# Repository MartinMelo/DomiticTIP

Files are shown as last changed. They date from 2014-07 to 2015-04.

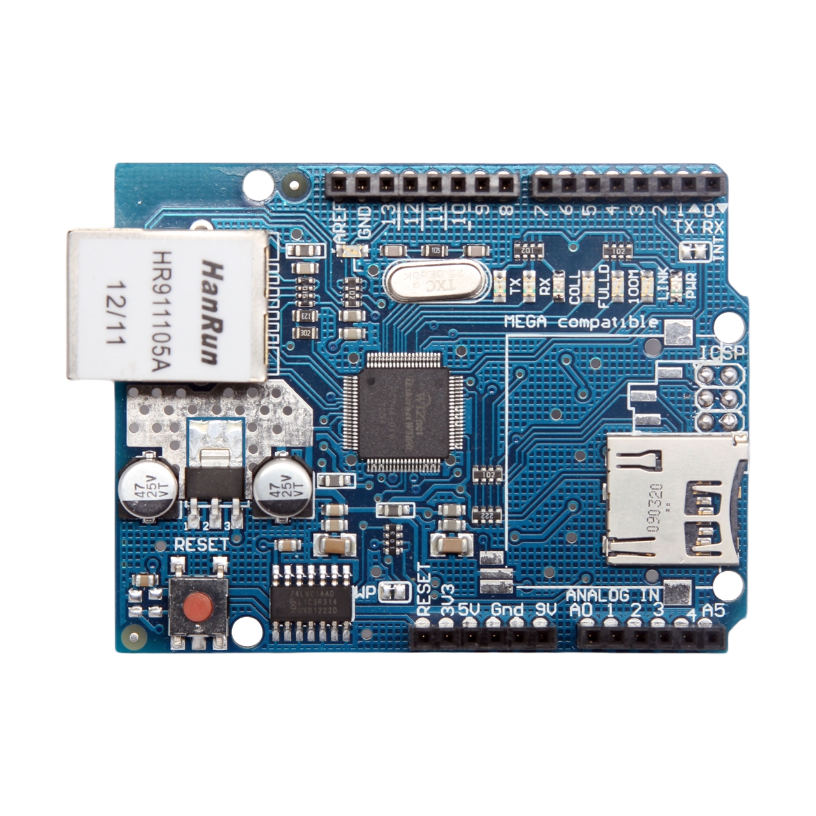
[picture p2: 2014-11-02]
Documentacion/Ethernet Shield Wiznet 5100.jpeg

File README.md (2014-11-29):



DomiticTIP 
==========

Integración de tecnología para control y automatización de espacio físico

## Prerequisitos/Instalación

### Bajar
Clonar `DomiticTIP` [repository](https://github.com/MartinMelo/DomiticTIP.git)
```
git clone https://github.com/MartinMelo/DomiticTIP.git
```

###Dependencias

Depende de varios otros programas:
- [node.js](http://www.nodejs.org/)
- [npm](https://www.npmjs.org/)

### Instalación

```
npm install
npm start
```

### Probar

Ir a Browser:
file://CLONE_DIR/DomiticTIP/examples/index.html

### Instalacion Arduino

Para cargar el firmware del microcontrolador sera necesario tener Inotool.
```
http://inotool.org/
```
Una vez instalado inotool, dentro de la carpeta del proyecto ejecutar lo siguiente:

```
cd Arduino
ino build 
ino upload
```
Tambien sera necesario copiar el archivo initstat.txt y serve.txt, que se encuentran en el directorio Arduino, dentro de la micro sd card que se va a utilizar en el ethernet shield.

### Como Correr El Servidor

Sera necesario ejecutar en distintas terminales las siguientes lineas por separado:

```
forever start server.js
forever start broker.js
forever start schedulerManager.js
forever start fingerprintDetector.js
```

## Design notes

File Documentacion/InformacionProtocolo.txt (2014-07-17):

Tipos de mensajes desde el server: 

Pedir que tiene arduino para ofrecer.
{
comand: 'exposeServices'
}
Informarle acciones a realizar.
{
comand: 'accion',
destino: 'seccion',
datos: otro JSON dependiendo el type.
}

Tipos de mensajes desde arduino:

Informar cambio de estado.
{
comand: 'refresh',
type: 'seccion',
data: otro json dependiendo el type. 
}
Informar que tiene arduino para ofrecer.
{
type: 'information'.
secciones: [],//cantidad variable que se va a utilizar para buscar en el json la info necesaria.
iluminacion: []//distintos ids/nombres de las luces que arduino va  saber usar.
sensores: []//distintos ids/nombres de los sensores que arduino va  saber usar.
climitizacion: []//distintos ids/nombres de los climatizadores que arduino va  saber usar.
seguridad: []//distintos ids/nombres de los dispositivos de seguridad() que arduino va  saber usar.
}

//Secciones:
iluminacion,sensores,climitizacion,seguridad, etc.

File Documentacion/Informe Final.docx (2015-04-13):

Trabajo de Inserción Profesional

Informe Final

Título:

Integración de tecnología para control y automatización de espacio físico.

Alumno:

Martin Alejandro Melo.

Director:

Ing. José Luis Di Biase.

Carrera:

Tecnicatura en Programación Informática.

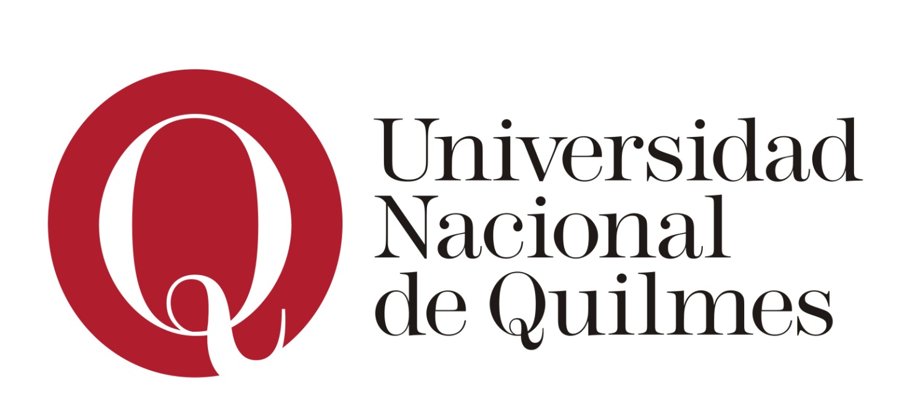
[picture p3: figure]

# Introducción

## Contexto

En la actualidad es cada vez más común y frecuente ver dispositivos inteligentes en nuestras vidas. Desde Smartphones hasta robots de servicios o domésticos, los cuales realizan tareas diarias la cuales pueden ser realizadas por una persona. Todos estos dispositivos se encuentran aislados entre ellos, es decir, no se comunican entre sí o con un dispositivo central. Si estos estuviesen comunicados o controlados por un sistema central, se podrían obtener mejores resultados.

## Problemática

El desafío del trabajo es poder centralizar información e interactuar con múltiples dispositivos y sensores electrónicos localizados remotamente.

No solo los dispositivos no están en el mismo espacio físico, sino que quien interactúa y los controla potencialmente está también en otro lugar.

Finalmente la idea es poder recolectar datos generados por los dispositivos, visualizarlos en tiempo real, agendar acciones futuras y poder cambiar su estado a partir de una aplicación web en internet.

# Objetivos

La empresa en la que actualmente me desempeño programando necesita tener una herramienta que sirva de control y automatización de ciertos espacios físicos (oficina, depósito, zona común, etc.). En este momento estos controles son llevados a cabo por empleados que los realizan diariamente cuando algún superior se lo indica dándole además las instrucciones necesarias para su realización.

Se necesita tener acceso a través de internet a un sitio web con la información de los distintos controles que se tengan los espacios físicos para corroborar estados, efectuar acciones o configurar tareas automatizadas para que se realicen según un calendario.

Los principales controles realizados son los siguientes:

- Iluminación: Se desea poder controlar la iluminación de determinados sectores de forma automática, es decir configurar su encendido y apagado determinando un calendario para el mismo o manualmente.
- Climatización: Esto sería idéntico que para la iluminación ya que determinados lugares del recinto cuentan con diferentes rangos necesarios de humedad y temperatura (por ejemplo: un depósito de documentos en papel o una habitación con servidores).
- Empleados: Se desea poder controlar la llegada y partida de los empleados al recinto a través de alguna forma de control como un lector de huellas digital.
- Seguridad: Se desea poder conocer el estado de los distintos puntos de acceso(puertas) al recinto.

Estos 4 controles principales se llevan a cabo diariamente y son de una importancia vital para la empresa.

La elaboración de este trabajo tuvo como objetivo principal desarrollar una herramienta que automatice todos los aspectos mencionados en la sección anterior. Dicha herramienta es intuitiva y de fácil acceso, a su vez esta es distribuida como software libre bajo la licencia MIT.

# Resumen

En la actualidad es cada vez más común y frecuente ver dispositivos inteligentes en nuestras vidas. Desde Smartphones hasta robots de servicios o domésticos, los cuales realizan tareas diarias la cuales pueden ser realizadas por una persona. Todos estos dispositivos se encuentran aislados entre ellos, es decir, no se comunican entre sí o con un dispositivo central. Si estos estuviesen comunicados o controlados por un sistema central, se podrían obtener mejores resultados.

El desafío del trabajo es poder centralizar información e interactuar con múltiples dispositivos y sensores electrónicos localizados remotamente.

No solo los dispositivos no están en el mismo espacio físico, sino que quien interactúa y los controla potencialmente está también en otro lugar.

La solución propuesta es la de desarrollar una herramienta la cual logre unir la electrónica y la programación para formar una solución capaz de simplificar tareas que día a día se realizan de forma presencial. Como por ejemplo verificar el estado de una puerta, encender o apagar luces, obtener diferentes datos a través de sensores que se encuentren en el recinto, etc. Todos estos se va a unir utilizando protocolos de comunicación entre los dispositivos y el programa central con el cual se van a comunicar. El usuario que utilice el sistema se podrá comunicar a través de un sitio web(Front-End).

# Desarrollo de la solución propuesta

## Descripción/Contexto General

Este proyecto se basó en los conceptos de Automatización y control de los espacios físicos y también en el concepto de Internet of Things para poder obtener una herramienta útil.

El Internet de las cosas o Internet Of Things es un término que se relacionan mucho con la web. Pero también resulta un concepto un poco abstracto para los no iniciados pese a que ha estado ganando bastante popularidad en el último tiempo. La idea que intenta representar queda bastante bien ilustrada por su nombre, cosas cotidianas que se conectan a Internet, pero que en realidad se trata de mucho más que eso.

La Domotica es un conjunto de sistemas capaces de automatizar una vivienda, que pueden estar integrados por medio de redes cuyo control goza de cierta ubicuidad, desde dentro y fuera del hogar. Se podría definir como la integración de la tecnología en el diseño inteligente de un recinto cerrado.

## Características de la solución desarrollada

Considerando los objetivos descriptos en este mismo documento, se creó una aplicación que cuenta con las siguientes funcionalidades:

- Encontrar y comunicarse con los distintos dispositivos físicos conectados a mi aplicación.
- Recolectar información de los distintos sensores que posea un dispositivo.
- Crear, editar y listar tareas automáticas, las cuales se ejecutaran en un determinado calendario y realizaran una acción determinada. Como por ejemplo cambiar el estado de una luz determinada.
- Crear, editar y listar configuraciones de climatización para los distintos sensores de un dispositivo.
- Crear, editar y listar Widgets, los cuales representan la información que se obtiene de los distintos dispositivos.
- Crear, editar y listar dispositivos, los cuales se utilizan para obtener información de los dispositivos físicos.
- Crear, editar y listar secciones, las cuales representan el lugar físico donde se encuentran los sensores.
- Personalizar la pagina principal con los distintos widgets.
- Registrarse para tener un perfil de usuario.
- Editar el perfil del usuario.
- Cambiar la clave del usuario.
- Obtener la lista de los controles de horario de llegada o partida del personal realizados.
- Obtener la lista de los empleados registrados.

## Hardware

El hardware es la parte que está formado por los componentes eléctricos y/o electrónicos que son necesarios para hacer que el sistema funcione. El mismo se encarga de suministrar información al sistema y a su vez al cual se le podrá pedir realizar distintos tipos de acciones estará basado en la plataforma Arduino.

### Componente base

Los componentes de base necesarios para que el sistema funcione son:

- Arduino Mega2560: Es utilizado como hardware principal al cual se tendrá conectado distintos tipos de circuitos y sensores.
- Ethernet Shield con chipset Wiznet W510: El cual es utilizado para la comunicación con la aplicación que utilizara el usuario.

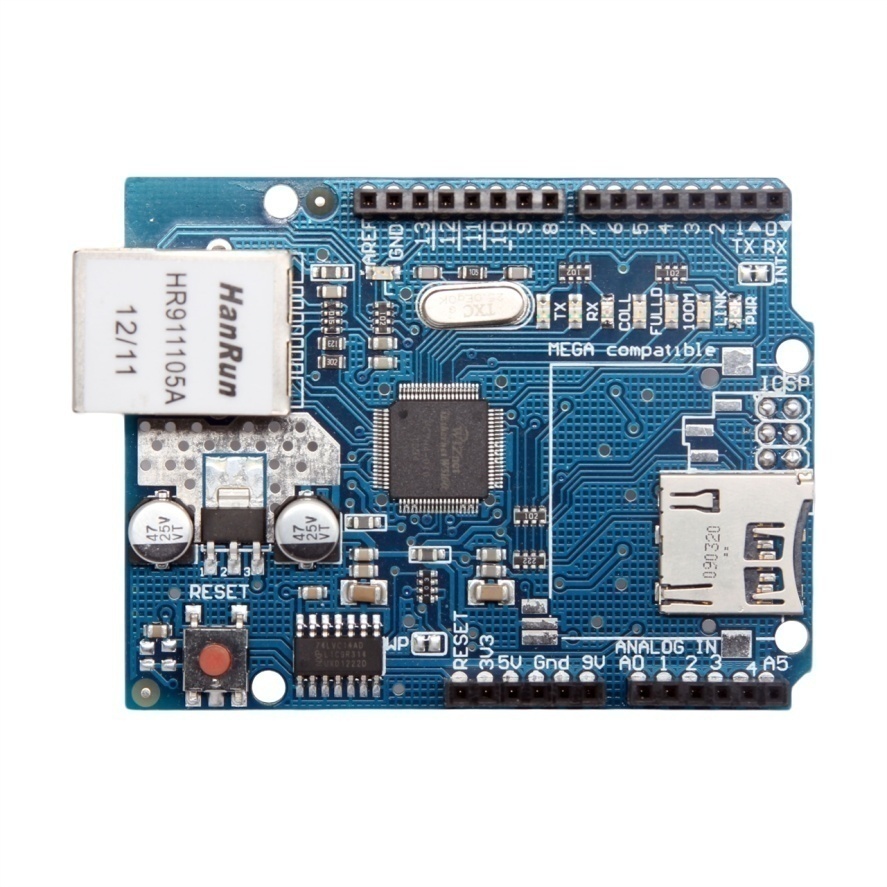
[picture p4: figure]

A los componentes anteriores se pueden añadir los sensores específicos los cuales se utilizan para extraer información del ambiente.

### Sensores específicos

El sensor de temperatura utilizado en el circuito impreso es un LM35DZ.

También se utilizaron ciertos componentes específicos para simular sensores de puerta o para controlar el cambio de estado de otros componentes electrónicos como las luces.

### Componentes específicos[^1]

Los componentes específicos utilizados son los siguientes:

- ULN2803. Es un array de Darlington que se utiliza para controlar las luces que se encuentran conectadas al circuito de las luces. Su hoja de datos es la siguiente: http://www.ti.com/lit/ds/symlink/uln2803.pdf (http://www.ti.com/lit/ds/symlink/uln2803a.pdf).
- Botones de estado normal abierto. Cada botón se utiliza para simular apertura de puertas.
- Resistencia 1K ohm. Se utilizan para eliminar el efecto "antena" de los cables que se conectan a las entrada del Arduino, estas resistencia van junto a los botones.

### Diagramas de conexión

Se agregan en el Anexo los esquemas de conexión de los componentes específicos que conforman el hardware.(Diagrama eléctrico y esquema en protoboard)

El primero de ellos pertenece al esquema de conexión de los componentes al micro controlador. La segunda imagen pertenece al esquema de conexión de los componentes utilizando un protoboard[^2].

## Firmware

El firmware es el software encargado de manejar directamente los dispositivos a nivel eléctrico.

Está programado en el lenguaje C y está grabado en la memoria del micro controlador.

En el mismo se incluyen las siguientes librerías:

- PubSubClient.
- ArduinoJson.

### PubSubClient

Esta librería permite la suscripción y publicación de mensajes contra un servidor que soporte el protocolo MQTT. Y es utilizado para enviar y recibir información desde los micro controladores.

### ArduinoJson

Permite el parseo y utilización del texto con formato JSON que se le envía al micro controlador con las instrucciones a realizar.

## Software

La aplicación tiene 3 partes bien diferenciadas ( Back-End, Middlewarey Front-End ). Cada uno de estos componentes cumple un rol determinado y son independientes. De manera que puedan funcionar los componentes en diferentes equipos.

Tanto el Back-End como el Front-End se encuentran construidas a partir del generador de código MeanJS. El cual permite generar aplicaciones web utilizando el Stack de aplicaciones (MongoDB, Express, AngularJS y NodeJS).Se utilizo esta herramienta ya que permite reutilizar funcionalidades comunes de los desarrollo web, lo cual ayudo a minimizar el tiempo de desarrollo.

### Front-End

El Front-End es el componente que hace de interfaz web a partir de la cual el usuario interactúa. Está desarrollado íntegramente con Javascript en particular con el framework AngularJS como base y múltiples bibliotecas adicionales.

En este componente se puede realizar lo siguiente:

- Crear, editar y listar tareas automáticas, las cuales se ejecutaran en un determinado calendario y realizaran una acción determinada. Como por ejemplo cambiar el estado de una luz determinada.
- Crear, editar y listar configuraciones de climatización para los distintos sensores de un dispositivo.
- Crear, editar y listar Widgets, los cuales representan la información que se obtiene de los distintos dispositivos.
- Crear, editar y listar dispositivos, los cuales se utilizan para obtener información de los controladores físicos.
- Crear, editar y listar secciones, las cuales representan el lugar físico donde se encuentran los sensores.
- Personalizar la pagina principal con los distintos widgets.
- Registrarse para tener un perfil de usuario.
- Editar el perfil del usuario.
- Cambiar la clave del usuario.
- Obtener la lista de los controles de horario de llegada o partida del personal realizados.
- Obtener la lista de los empleados registrados.

### Back-End

El Back-End es el componente encargado de servir las páginas web y de la persistencia de datos.
Está desarrollado utilizando NodeJS.

Las funcionalidades de este componente son las siguientes:

- Provee las páginas web que el Front-End mostrara al usuario.
- Almacenar en base de datos los registros de control de llegada o partida de los empleados.
- Almacenar en base de datos la información de widgets creados por el usuario.

También se utilizan las siguientes librerías y Frameworks:

- MongoDB: Es el motor de la base de datos.
- Mongoose: Utilizado para administrar la base de datos.
- Express: Utilizado para unir el Back-End con el Front-End ya que es el que provee una vía de comunicación entre ambos puntos.
- node-schedule: Utilizada para llevar a cabo las tareas automáticas que se creen en la aplicación.

### Middleware

El Middleware es la parte de la aplicación que permite la comunicación entre los distintos dispositivos y el Front-End. Hace de nexo, intercambiando datos entre el Front-End y los distintos dispositivos de control.

Por ejemplo cuando el usuario desea encender una luz, el middleware será el encargado de informarle al Dispositivo de llevar a cabo esta acción.

También fue desarrollado con NodeJS.

Además se utilizan dos protocolos de comunicación:

- Mqtt: Se utilizo Mosca Servidor de mensajes que permite la comunicación entre las distintas aplicaciones
- Websockets: Se utilizó Socket.io para crear un servidor de mensajes web que habilita la comunicación directa entre el Front-End y los dispositivos.
- Mosca: En la aplicación se utiliza como servidor de mensajes principal para permitir la comunicación entre todos los servicios.

Esta parte está alojada en el mismo servidor que el Back-End, ya que no es necesaria una separación física. Pero esta se puede realizar de ser necesaria.

## Interconexión

Las distintas partes de la aplicación se comunican utilizando un protocolo diferente para cada parte.

El Front-End el cual de entre las diversas funcionalidades que posee tiene la cualidad de "comunicarse" con los controladores, esta función no se lleva a cabo directamente. El flujo de comunicación se da entre 3 partes y de la siguiente manera:

1. El Front-End demanda la información de un sensor o la petición de realizar una acción determinada.
2. El Middleware recibe esta petición y se la envía al controlador que está a la espera de estas peticiones.
3. El controlador recibe, procesa y contesta si es necesario la petición hacia el Middleware, el cual se lo devuelve al Front-End si es que está a la espera de una repuesta.

El siguiente grafico describe la conexión del sistema.

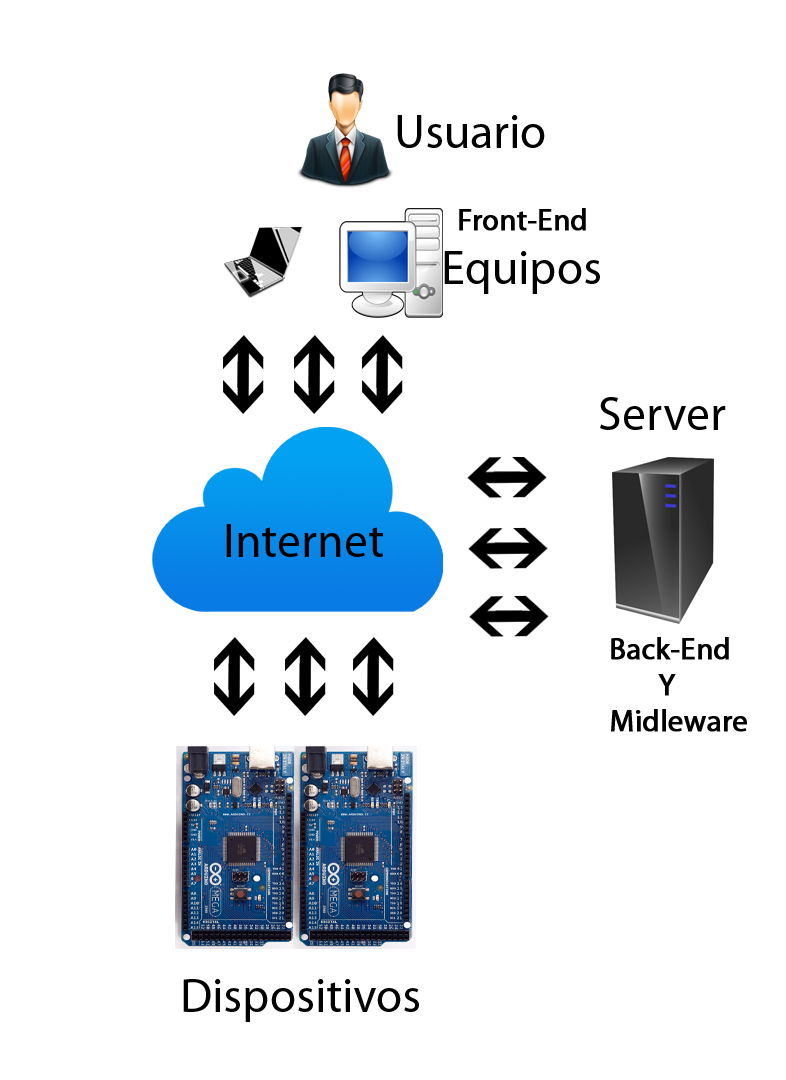
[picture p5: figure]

### Protocolo de comunicación

El protocolo de comunicación utilizado se basa en el envió de pequeñas porciones de texto con el formato JSON. Que contienen pequeña información de las acciones que se desean realizar.

#### Contenidos de los mensajes

Para esta aplicación se creó una estructura básica y sencilla para poder comunicarse e interactuar con los dispositivos y viceversa.

La estructura para comunicarse con los dispositivos está formada de la siguiente manera:

{

"command": "comando",

"destino": "destino",

"datos": {}

}

Donde el "comando " es el tipo de petición a realizar, pudiendo ser "accion" o "exponerServicios". Siendo la primera la cual informa que el dispositivo va a tener que realizar una acción como por ejemplo encender una luz o enviar información de un sensor, Y la segunda para que el dispositivo envié la información de los servicios que provee el mismo.

El "destino" es para marcar que tipo de petición se desea como por ejemplo si es iluminación, sensores o climatización. Si el comando fue "exponerServicios" este campo sirve para denotar por cual servicio se está preguntando, para este comando el campo puede tener los siguientes valores: "luz", "sensor" y "todo".

El campo datos es otro json que depende de la sección de destino, ya que la información es diferente para cada sección. Para la sección "Iluminación" el campo "datos" tendrá la siguiente estructura:

{

"id": "número de luz",

"estado": "valor"

}

Donde "id" tendrá el número que pertenece a una luz que el dispositivo tiene asignado. Y "estado" será "on" o "off" siendo el primero para denotar el encendido y el segundo para denotar el apagado de la luz.

Para la sección "sensores" el campo "datos" tendrá la siguiente estructura:

{

"id": "tipo de sensor",

"posicion": "nombre de la posición"

}

Donde "id" pueden ser "temperatura" o "puertas", siendo el primero para pedir información de sensores que son numéricos(por ejemplo un sensor de temperatura ambiental con un rango de valores entre -50 y 150 grados Celsius) y el segundo para sensores que estados de forma booleana, por ejemplo un sensor de apertura donde se desea tener solo 2 valores posibles(true para denotar un estado y false para denotar otro, pudiendo ser el primero para puerta cerrada y el segundo para puerta abierta).

El campo "posicion" se utiliza para denotar el sensor del cual se desea obtener la información.

La respuesta de los dispositivos son únicamente 2, siendo una de ellas para responder a las peticiones de información de un sensor donde el valor de la respuesta es el valor resultado(un número o un boolean).

La segunda respuesta es a la petición de exponer los servicios. Esta ultima puede tener 3 formas diferentes dependiendo la petición realizada al dispositivo. La primera forma es en respuesta a la petición con el valor de sección "todo" la cual si bien está implementado no se utiliza, y tendrá la siguiente estructura:

{

"suscripto": "nombre del dispositivo",

"tipos": [

{

"nombre": "luz"

},

{

"nombre": "sensor"

}

]

}

La segunda forma es en respuesta a la petición con el valor de sección "luz" y tendrá la siguiente estructura:

{

"luz": [

{

"nombre": "nombre que identifica la luz",

"topico": "valor numérico correspondiente a la luz"

},

]

}

La tercer forma es en respuesta a la petición con el valor de sección "sensor" y tendrá la siguiente estructura:

{

"sensor": [

{

"nombre": "nombre del sensor",

"topico": "tópico destino",

"tipo": "tipo de datos que se obtiene del sensor"

}

]

}

La información obtenida de las respuesta a la petición de exponer servicios se utiliza para saber cómo interactuar con el dispositivo.

# Problemas resueltos

Durante el desarrollo temprano de la aplicación es donde tuve más problemas relacionados a la forma de uso de las distintas herramientas que forman la aplicación.

La forma de comunicación entre las distintas partes de la aplicación y los distintos dispositivos fue un problema bastante complicado de resolver, ya que al no tener una misma herramienta para comunicar todas las partes que forman la aplicación hizo que sea necesario un punto de unión para llevar a cabo la comunicación. Esta unión la lleva a cabo el Middleware.

Por último, no lo considero un problema, pero todas las herramientas utilizadas en la aplicación fueron completamente nuevas para mí. Esto hizo que sea un poco más complejo desarrollar, haciendo que quizás existan cosas que se hubieran podido desarrollar en menos tiempo o de manera más sencilla.

# Conclusiones

Luego de haber estado trabajando en este proyecto durante los últimos meses, hice una presentación interna en la empresa para verificar si se habían alcanzado los objetivos propuestos. Tuve una devolución satisfactoria en donde expresaban su voluntad para utilizar este proyecto como base para próximos productos.

Este proyecto sirvió para mostrar un prototipo usable e innovador, movilizando pocos recursos. Igualmente mencionaron detalles para mejorar la usabilidad de la interfaz, de todas formas desde el desarrollo se hizo hincapié en mostrar un prototipo funcional de la aplicación.

Finalmente, este desarrollo está abierto a sugerencias que aporten a mejorarlo, al ser un proyecto de código abierto, cualquiera puede colaborar con código que resuelva errores o agregue nuevas funcionalidades. Más información en: https://github.com/MartinMelo/DomiticTIP

# Anexos

## Anexo Hardware

### Arduino

#### Como nace

La creación de Arduino se inicio en el año 2005 y fue un proyecto para los estudiantes de un instituto en Ivrea Italia. Este proyecto surgió de la necesidad de contar con un dispositivo de bajo costo y que se pueda utilizar con cualquier sistema operativo.

#### ¿Qué es?

Arduino es una plataforma de hardware libre, basada en una placa con un micro controlador y un entorno de desarrollo, diseñada para facilitar el uso de la electrónica en proyectos multidisciplinares.

El hardware consiste en una placa con un micro controlador Atmel AVR (http://es.wikipedia.org/wiki/AVR). La siguiente imagen pertenece una placa Arduino Mega2650.

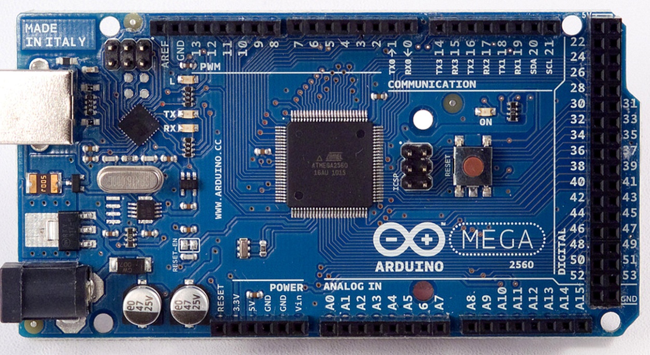
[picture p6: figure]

Actualmente existen muchos entornos de desarrollos para crear programas para Arduino, los cuales se encuentran programados en diferentes lenguajes como C, Java, y Python.

La sintaxis del lenguaje de programación Arduino es una versión simplificada de C/C++.

#### ¿Qué resuelve?

Se utilizó para crear un dispositivo capaz de poder comunicarse en ambos sentidos con la aplicación que utiliza el usuario y que a su vez se pueda utilizar para efectuar distintas acciones basándose en la información que se le suministre a través de un protocolo específico. A su vez, el mismo está conectado a distintos circuitos electrónicos que le proveen efectuar las acciones anteriormente mencionadas y también la obtención de información de los sensores que posea.

### Diagramas del Hardware

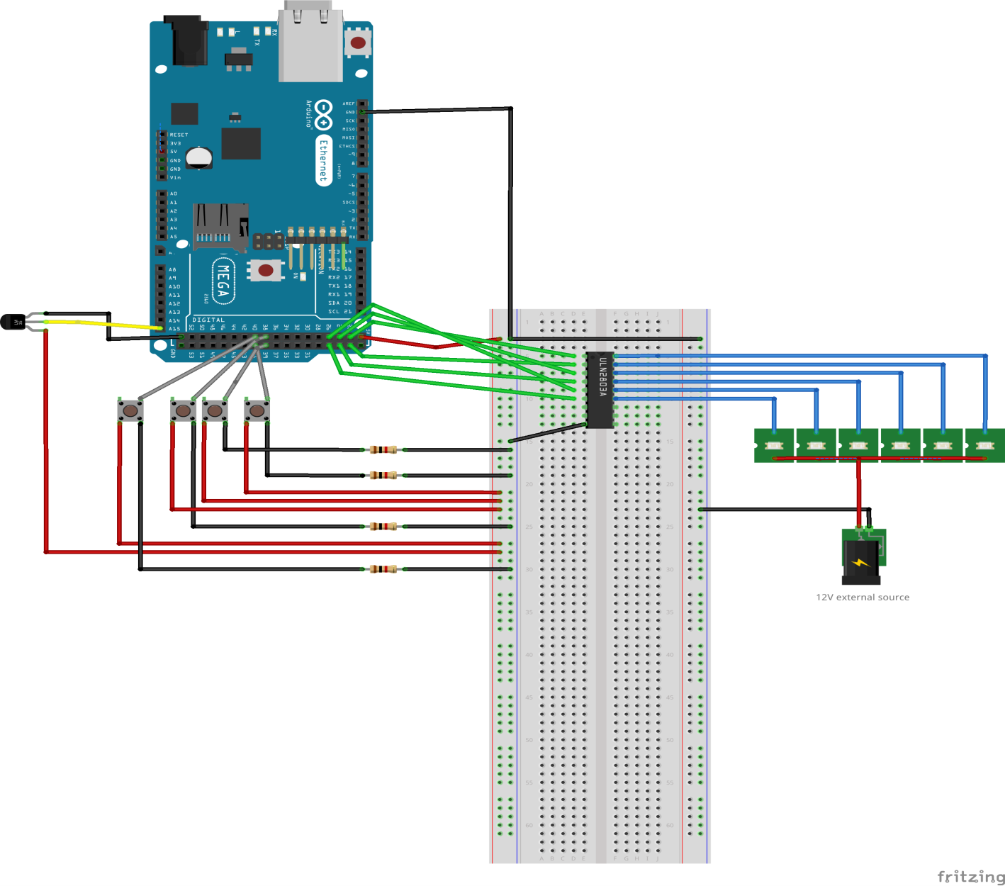
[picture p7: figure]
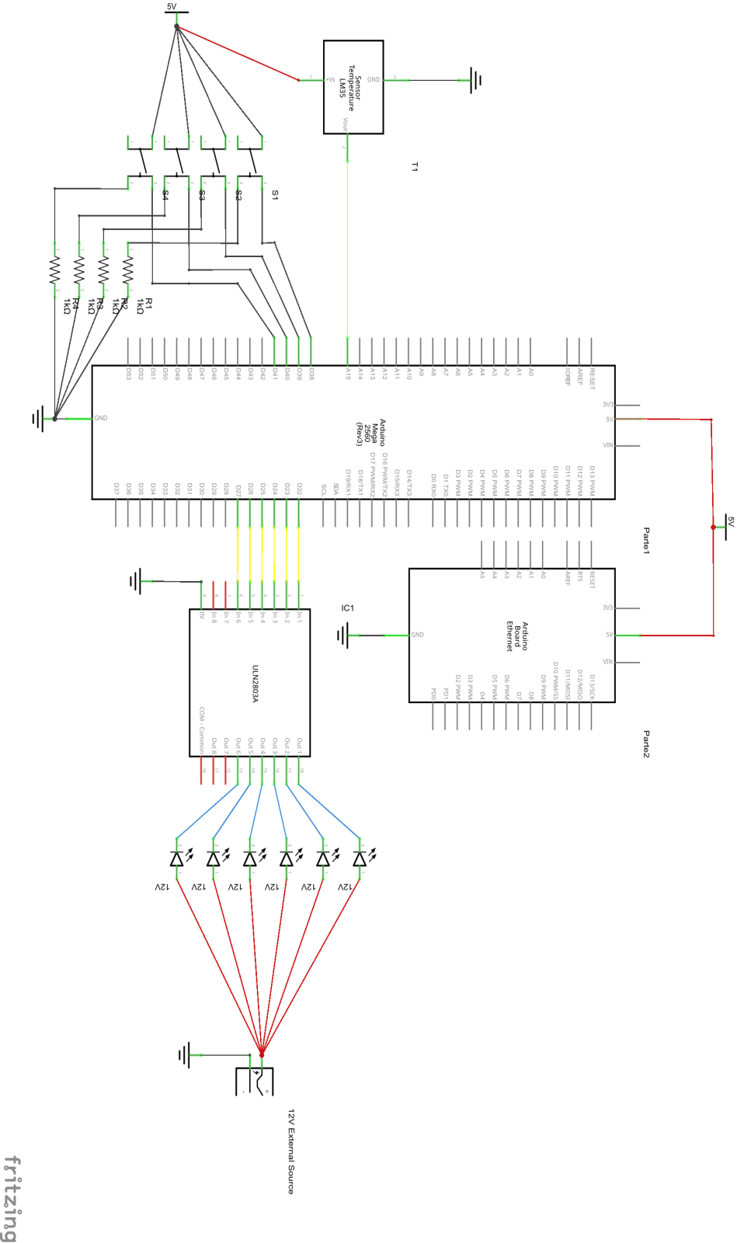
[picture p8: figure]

### Sensor de temperatura

El modelo del sensor es LM35DZ y el fabricante es Texas Instruments. Posee un rango de medición de -55° a 150° Celsius. El mismo puede ser reemplazado por otro sensor de similares características. Su hoja de datos es la siguiente:

http://www.ti.com.cn/cn/lit/ds/symlink/lm35.pdf

## Anexo Software

### M2M

M2M (Machine to Machine o Máquina a Máquina) es un concepto genérico que se refiere al intercambio de información o comunicación en formato de datos entre dos máquinas remotas.

### MQTT

Message Queue Telemetry Transport (MQTT) (http://mqtt.org/) es un protocolo de conectividad enfocado a M2M (machine-to-machine) y al IOT (Internet of Things) ya que se ha diseñado para ser un protocolo de mensajería extremadamente ligero basado en TCP.

Es útil para conexiones con sitios remotos donde se posee una alta latencia y el ancho de banda es muy importante.

Una característica muy importante es que al ser un protocolo tan ligero existen clientes y servidores MQTT en diversos lenguajes.

### Mosca

Es un bróker de mensajería, con lo cual es un mecanismo mediador de la comunicación entre aplicaciones y/o dispositivos, permitiendo minimizar el grado de conocimiento mutuo que estos necesitan tener, para poder intercambiar mensajes, implementando así efectivamente su desacoplamiento (http://es.wikipedia.org/wiki/Dise%C3%B1o_estructurado).

El propósito del bróker es recibir los mensajes entrantes desde las aplicaciones y llevar a cabo determinadas acciones con ellas.

### Socket.IO

Socket.io es una librería que permite manejar eventos en tiempo real mediante una conexión TCP y todo ello en Javascript. Es realmente potente y permite hacer todo tipo de aplicaciones en tiempo real, como por ejemplos servicios de mensajería/chats. Ya que permite la comunicación bidireccional entre clientes web y servidor. Esta librería está compuesta de 2 partes, la primera de ellas es la que corre en el navegador del cliente y la otra de ellas es la que corre en el servidor de la aplicación. Ambas partes son casi idénticas y ambas se basan en el manejo de eventos.

Socket.io utiliza principalmente el protocolo de Websockets, aunque también permite utilizar polling manteniendo la misma interfaz. A su vez también contiene características extra entre las cuales se incluye la posibilidad de realizar broadcast a múltiples sockets, almacenar información asociada a cada cliente y procesar entrada/salida de forma asincrónica.

### ¿Qué es JSON?

JSON (Javascript Object Notation - Notación de Objetos de Javascript) es un formato ligero de intercambio de datos. Leerlo y escribirlo es simple para humanos, mientras que para las máquinas es simple interpretarlo y generarlo. Está basado en un subconjunto del Lenguaje de Programación Javascript (http://javascript.crockford.com/), Standard ECMA-262 3rd Edition - Diciembre 1999 (http://www.ecma-international.org/publications/files/ecma-st/ECMA-262.pdf).

JSON es un formato de texto que es completamente independiente del lenguaje pero utiliza convenciones que son ampliamente conocidos por los programadores de la familia de lenguajes C, incluyendo C, C++, C#, Java, Javascript, Perl, Python, y muchos otros. Estas propiedades hacen que JSON sea un lenguaje ideal para el intercambio de datos.

JSON está constituido por dos estructuras:

- Una colección de pares de nombre/valor. En varios lenguajes esto es conocido como un objeto, registro, estructura, diccionario, tabla hash, lista de claves o un arreglo asociativo.
- Una lista ordenada de valores. En la mayoría de los lenguajes, esto se implementa como arreglos, vectores, listas o secuencias.

Estas son estructuras universales; virtualmente todos los lenguajes de programación las soportan de una forma u otra. Es razonable que un formato de intercambio de datos que es independiente del lenguaje de programación se base en estas estructuras.

En JSON, se presentan de estas formas:

Un objeto es un conjunto desordenado de pares nombre/valor. Un objeto comienza con { (llave de apertura) y termine con } (llave de cierre). Cada nombre es seguido por : (dos puntos) y los pares nombre/valor están separados por , (coma).

Un arreglo es una colección de valores. Un arreglo comienza con [ (corchete izquierdo) y termina con ] (corchete derecho). Los valores se separan por , (coma).

Un valor puede ser una cadena de caracteres con comillas dobles, o un número, o true o false o null, o un objeto o un arreglo. Estas estructuras pueden anidarse.

Una cadena de caracteres es una colección de cero o más caracteres Unicode, encerrados entre comillas dobles, usando barras divisorias invertidas como escape. Un carácter está representado por una cadena de caracteres de un único carácter. Una cadena de caracteres es parecida a una cadena de caracteres C o Java.

Un número es similar a un número en C o Java, excepto que no se usan los formatos octales y hexadecimales.

Los espacios en blanco pueden insertarse entre cualquier par de símbolos.

Un pequeño ejemplo de json es el siguiente:

{

"nombre": "cofre simple",

"descripcion": "soy un cofre simple de madera",

"cantidad": 3,

"elementos": [

{

"nombre": "Espada de diamantes",

"id": 276

},

{

"nombre": "Disco Strad",

"id": 2264

},

{

"nombre": "mesa de encantamiento",

"id": 116

}

]

}

### MongoDB

Es un sistema de base de datos (http://es.wikipedia.org/wiki/Base_de_datos) NoSQL (http://es.wikipedia.org/wiki/NoSQL) orientado a documentos, desarrollado bajo el concepto de código abierto (http://es.wikipedia.org/wiki/C%C3%B3digo_abierto).

En vez de guardar los datos en tablas como se hace en las base de datos relacionales, MongoDB guarda estructuras de datos en documentos tipo JSON (http://es.wikipedia.org/wiki/JSON) con un esquema dinámico (formato BSON (http://es.wikipedia.org/wiki/BSON)), haciendo que la integración de los datos en ciertas aplicaciones sea más fácil y rápida.

### Express

Es un Framework para NodeJS diseñado para construir tanto sitios web simples como complejos y a su vez aplicaciones web hibridas.

### Node-Schedule

Es un planificador de tareas flexibles tanto cron-like como non-cron-like para NodeJS. El cual permite programar tareas para realizar funciones arbitrarias en fechas específicas, con reglas de recurrencia opcionales. Utiliza un solo timer en un momento dado (en lugar de reevaluar próximos trabajos cada segundo/minuto).El mismo es MIT-License.

### Malhar-angular

Librería que provee el uso de componentes y directivas para utilizar Dashboard con Widgets en el Front-End.

### NodeJS

Es un entorno de programación para el Back-End basado en el lenguaje de programación ECMAScript (http://es.wikipedia.org/wiki/ECMAScript), asincrónico, con Entrada/Salida (http://es.wikipedia.org/wiki/I/O) de datos en una arquitectura orientada a eventos (http://es.wikipedia.org/wiki/Programaci%C3%B3n_dirigida_por_eventos) y basado en el motor V8 (http://es.wikipedia.org/wiki/V8_(motor_JavaScript)) de Google. Fue creado con el enfoque de ser útil en la creación de programas de red altamente escalables, como por ejemplo, servidores web (http://es.wikipedia.org/wiki/Servidor_web).

### MeanJS

Es una solución Javascript full stack que ayuda a crear aplicaciones web de producción rápidas, robustas y fáciles de mantener usando MongoDB, Express, AngularJS y Node.js.

## Anexo Extra

### Licencia MIT

Esta licencia permite reutilizar el software así licenciado tanto para ser software libre (http://es.wikipedia.org/wiki/Software_libre) como para ser software no libre (http://es.wikipedia.org/wiki/Software_no_libre), permitiendo no liberar los cambios realizados al programa original.

También permite licenciar dichos cambios con licencia BSD (http://es.wikipedia.org/wiki/Licencia_BSD), GPL (http://es.wikipedia.org/wiki/Licencia_p%C3%BAblica_general_de_GNU), u otra cualquiera que sea compatible (es decir, que cumpla las cláusulas de distribución).

Con esta licencia se tiene software libre. Ejemplos en los que podría interesar su aplicación serían las licencias duales (http://es.wikipedia.org/wiki/Licencia_dual), si se pretende difundir un estándar (http://es.wikipedia.org/wiki/Norma_(tecnolog%C3%ADa)) mediante una implementación de referencia, o si simplemente se pretende que el producto sea Libre sin mayores consideraciones.

### Internet Of Things

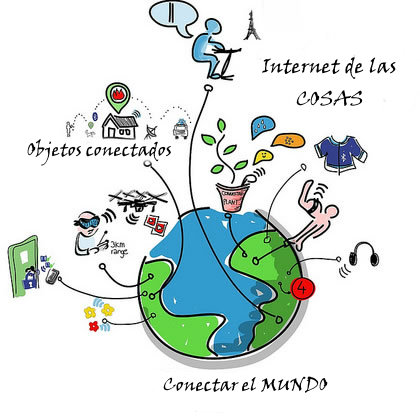
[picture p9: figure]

El Internet de las cosas o Internet Of Things es un término que se relacionan mucho con la web. Pero también resulta un concepto un poco abstracto para los no iniciados pese a que ha estado ganando bastante popularidad en el último tiempo. La idea que intenta representar queda bastante bien ilustrada por su nombre, cosas cotidianas que se conectan a Internet, pero que en realidad se trata de mucho más que eso.

Para entender de qué va el internet de las cosas debemos también comprender que sus fundamentos no son en lo absoluto nuevos. Desde hace unos 30 años que se viene trabajando con la idea de hacer un poco más interactivos todos los objetos de uso diario. Planteos como el hogar inteligente o casa del mañana, han evolucionado antes de que nos demos cuenta en el hogar conectado para entrar al internet de las cosas.

El Internet de las cosas potencia objetos que antiguamente se conectaban mediante circuito cerrado, como comunicadores, cámaras, sensores, y demás, y les permite comunicarse globalmente mediante el uso de la red de redes.

Si tuviéramos que dar una definición del internet de las cosas probablemente lo mejor sería decir que se trata de una red que interconecta objetos físicos valiéndose de la red. Los mentados objetos se valen de sistemas embebidos, o lo que es lo mismo, hardware especializado que le permite no solo la conectividad a internet, sino que además programa eventos específicos en función de las tareas que le sean dictadas remotamente (por ejemplo desde nuestro celular mientras trabajamos en la oficina).

### Automatización y control de los espacios físicos

Es también conocida como Domotica, la cual es un conjunto de sistemas capaces de automatizar una vivienda, aportando servicios de gestión energética, seguridad, bienestar y comunicación, y que pueden estar integrados por medio de redes interiores y exteriores de comunicación, cableadas o inalámbricas, y cuyo control goza de cierta ubicuidad, desde dentro y fuera del hogar. Se podría definir como la integración de la tecnología en el diseño inteligente de un recinto cerrado.

# Referencias

[1]Paulo Novais, Davy Preuveneers, Juan Manuel Corchado Rodríguez; Ambient Intelligence - Software and Applications: 2nd International Symposium on Ambient Intelligence, Springer, 2011.

[2] Rubén Saavedra Silveira, Automatización de viviendas y edificios, Ediciones CEAC, 2009.

[3] James Gerhart, Home Automation and Wiring, McGraw Hill Professional, 1999.

[4] Jamari Harmon, The Home Automation, Bookpubber, 2014.

[5] David Flanagan, JavaScript: The Definitive Guide, O'Reilly Media, Inc., 2011.

[6] Gary Shelly, Denise Woods, HTML: Introductory Concepts and Techniques, Cengage Learning, 2008.

[7] Brian W. Kernighan, Dennis M. Ritchie, El Lenguaje de Progra C, Pearson Educación, 1991.

## Referencias Adicionales

http://www.wisegeek.com/what-is-domotics.htm

https://angularjs.org/

http://jquery.com/

http://www.json.org/json-es.html

http://nodejs.org/

https://github.com/bblanchon/ArduinoJson

http://knolleary.net/arduino-client-for-mqtt/

[^1] Todos estos componentes son de bajo costo y pueden ser adquiridos en cualquier local donde vendan componentes electrónicos
[^2] Es un tablero con orificios conectados eléctricamente entre sí, en el cual se pueden insertar componentes electrónicos y cables para el armado y prototipado de circuitos electrónicos y sistemas similares.

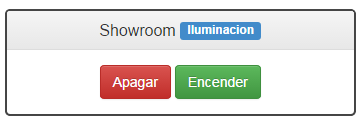
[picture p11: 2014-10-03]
public/modules/widgets/img/iluminacion.png

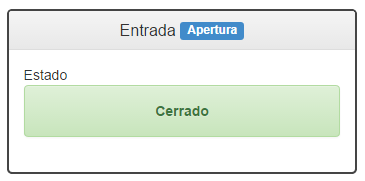
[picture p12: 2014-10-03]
public/modules/widgets/img/apertura.png

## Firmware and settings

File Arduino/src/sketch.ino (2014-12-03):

#include <SPI.h>
#include <Ethernet.h>
#include <PubSubClient.h>
#include <JsonParser.h>
#include <SD.h>

//Configuracion Ethernet Shield.
byte mac[]    = {  0xDE, 0xED, 0xBA, 0xFE, 0xFE, 0xED };
byte server[] = { 192, 168, 2, 1 };//IP del broker MQTT
byte ip[]     = { 192, 168, 2, 20 };
//Estados de las puertas
boolean patio;
boolean entrada;
boolean showroom;
boolean garage;
//Para parsear el json recibido o para enviar
char message_buff[100];
JsonParser<32> parser;
// Callback function header
void callback(char* topic, byte* payload, unsigned int length);

//aca manejo lo que me envian
void callback(char* topic, byte* payload, unsigned int length) {
  //obtengo el mensage enviado
  int i;
  for(i=0; i<length; i++) {
    message_buff[i] = payload[i];
  }
  message_buff[i] = '\0';
  Serial.println("Mensaje Recibido :" + String(message_buff));
  
  //Parseo el Json recibido
  JsonHashTable hashTable = parser.parseHashTable(message_buff);
  
  //Manejo el pedido recibido.
  String comando = hashTable.getString("comando");
  if(comando == "exponerServicios"){
     String servicio = hashTable.getString("servicio");
     exponerServicios(servicio);
  }
  if(comando == "accion"){
    realizarAccion(hashTable);
  }
}


EthernetClient ethClient;
PubSubClient client(server, 1883, callback, ethClient);

void setup()
{
  Serial.begin(9600);
  Ethernet.begin(mac, ip);
  configurarPlaca();
  configurarSDCard();
  cargarEstadoInicial();
}
void configurarSDCard(){
  if (!SD.begin(4)) {
    Serial.println("Sd card initialization failed!");
    return;
  }
  Serial.println("Sd card initialization done.");
  
}
//Carga el estado inicial guardado en la sd card.
void cargarEstadoInicial(){
  if (SD.exists("initStat.txt")) {
    File configuracion = SD.open("initStat.txt");
   //leo todo el archivo de estados
    String temp;
    char data;
    // make data to String;
    while ((data = configuracion.read()) >= 0) 
    {
     temp = temp + data;
    }
  //Cierro el archivo de estados
    configuracion.close();
    int largo = temp.length();
    //Parseo el Json que tiene los datos.
    int i;
    for(i=0; i< largo ; i++) {
      message_buff[i] = temp[i];
    }
    message_buff[i] = '\0';
    //Parseo el Json recibido
    JsonHashTable hashTable = parser.parseHashTable(message_buff);
    JsonArray lucesEncendidas = hashTable.getArray("lucesEncendidas");
    configurarLuces(lucesEncendidas);
  }else{
    Serial.println("el archivo no existe");
  }
}
//Enciende las luces.
void configurarLuces(JsonArray lucesArray){
  int i = 0;
  for(i; i < lucesArray.getLength();i++){
    int l = lucesArray.getLong(i);
    prenderLuz(l);
  }
  Serial.println("Luces Encendidas");
}
void prenderLuz(int luz){
  digitalWrite(luz , HIGH);
}
//Configuro los pines.
void configurarPlaca(){
  //SD Card
  pinMode(10, OUTPUT);
  //FIN SD Card
  //Luces
  int i=22;
  for(i; i<=28;i++){
    pinMode(i, OUTPUT);
  }
  //Fin Luces
  //Puertas
  i=38;
  for(i; i<=41;i++){
    pinMode(i, INPUT);
  }
  //Fin Puertas
  //Sensores
  pinMode(A15 , INPUT); //LM35DZ
  //Fin Sensores
  
  //cargo el estado inicial de los sensores
  estadosDePuertaInicial();
}
void estadosDePuertaInicial(){
  entrada =digitalRead(38);
  showroom =digitalRead(39);
  patio =digitalRead(40);
  garage =digitalRead(41);
}
void loop()
{
  client.loop();
  if(!client.connected()){
    client.connect("ard1");
    suscribirse();
  }
  chequearPuertas();
}
//Envio todo el estado completo del microcontrolador.
void refresh(){
}

//me suscribo.
void suscribirse(){
  client.subscribe("ard1");
  client.subscribe("discover");
  client.subscribe("ard1/discover");
}


//Realiza la accion pedida.
void realizarAccion(JsonHashTable hashTable){
  String destino = hashTable.getString("destino");
  String datos = hashTable.getString("datos");
  int largo = datos.length();
  //Parseo el Json que tiene los datos.
  int i;
  for(i=0; i< largo ; i++) {
    message_buff[i] = datos[i];
  }
  message_buff[i] = '\0';
  JsonHashTable info = parser.parseHashTable(message_buff);
  if(destino == "iluminacion"){
    accionesIluminacion(info);
  }
  if(destino == "sensores"){
    accionesSensores(info);
  }
  if(destino == "climatizacion"){
    accionesClimatizador(info);
  }
  
}
void accionesClimatizador(JsonHashTable hashTable){
  int pin = hashTable.getLong("id");
  String estado = hashTable.getString("estado");
  String sensor = hashTable.getString("sensor");
  int grados = hashTable.getLong("grados");
  //No hago nada aun.
}
void accionesIluminacion(JsonHashTable hashTable){
  int pin = hashTable.getLong("id");
  String estado = hashTable.getString("estado");
  if(estado == "on"){
    digitalWrite(pin , HIGH);
  }
  else{
     digitalWrite(pin , LOW);
  }
}
void accionesSensores(JsonHashTable hashTable){
  String id = hashTable.getString("id");
  String posicion = hashTable.getString("posicion");
  if(id == "temperatura"){
     publicarEstadoSensorTemperatura(posicion);
  }
  if(id == "puertas"){
     publicarEstadoPuerta(posicion);
  }
  
}
void publicarEstadoPuerta(String posicion){
  if(posicion == "entrada"){
    if(digitalRead(38) == HIGH){
        client.publish("resp/ard1/entrada", "true");
    }else{
        client.publish("resp/ard1/entrada", "false");
    }
  
  }
  if(posicion == "showroom"){
    if(digitalRead(39) == HIGH){
        client.publish("resp/ard1/showroom", "true");
    }else{
        client.publish("resp/ard1/showroom", "false");
    }
  
  }
  if(posicion == "patio"){
    if(digitalRead(40) == HIGH){
       client.publish("resp/ard1/patio", "true");
    }else{
       client.publish("resp/ard1/patio", "false");
    }
  }
  if(posicion == "garage"){
    if(digitalRead(41) == HIGH){
       client.publish("resp/ard1/garage", "true");
    }else{
       client.publish("resp/ard1/garage", "false");
    }
  }
}
void publicarEstadoSensorTemperatura(String posicion){
  String sensor= String(random(1,30));
  char temp[2];
  sensor.toCharArray(temp,2);
  if(posicion == "living"){
    client.publish("resp/ard1/living/temp",temp);
  }
  if(posicion == "basement"){
    client.publish("resp/ard1/basement/temp",temp);
  }
  if(posicion == "ambiente"){
    int a = (4.9 * analogRead(A15) * 100.0) / 1024;   
    char b[3];
    String str=String(a); //converting integer into a string
    str.toCharArray(b,3);
    client.publish("resp/ard1/ambiente/temp",b);
  }
}
//Expone todo lo que tiene el microcontrolador.
void exponerServicios(String servicio){
  char* json;
  if(servicio == "todo"){
    json= "{\"suscripto\": \"ard1\",\"tipos\": [{\"nombre\":\"luz\"},{\"nombre\": \"sensor\"}]}";
  }
  if(servicio == "luz"){
    json="{\"luz\": \[{\"nombre\": \"Entrada\",\"topico\": 22},{\"nombre\": \"Showroom\",\"topico\": 23}]}";
  }
  if(servicio == "sensor"){
    json="{\"sensor\": [{\"nombre\": \"ambiente\",\"topico\": \"ard1/ambiente/temp\",\"tipo\": \"numero\"},{\"nombre\": \"patio\",\"topico\": \"ard1/patio\",\"tipo\": \"bool\"}]}";
  }
    client.publish("resp/discover", json); 
}
void chequearPuertas(){
  boolean estadoEntrada = digitalRead(38) == HIGH;
  if(estadoEntrada != entrada){
     entrada= digitalRead(38) == HIGH;
     if(entrada){
        client.publish("resp/ard1/entrada", "true");
    }else{
        client.publish("resp/ard1/entrada", "false");
    }
  }
   boolean estadoShowroom = digitalRead(39) == HIGH;
   if(estadoShowroom != showroom){
     showroom = digitalRead(39) == HIGH;
     if(showroom){
        client.publish("resp/ard1/showroom", "true");
    }else{
        client.publish("resp/ard1/showroom", "false");
    }
  }
   boolean estadoPatio = digitalRead(40) == HIGH;
   if(estadoPatio != patio){
     patio = digitalRead(40) == HIGH;
     if(patio){
        client.publish("resp/ard1/patio", "true");
    }else{
        client.publish("resp/ard1/patio", "false");
    }
  }
   boolean estadoGarage =digitalRead(41) == HIGH;
   if(estadoGarage != garage){
     garage= digitalRead(41) == HIGH;
     if(garage){
        client.publish("resp/ard1/garage", "true");
    }else{
        client.publish("resp/ard1/garage", "false");
    }
  }
}

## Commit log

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2014-07-09 Revert "se modifo el sketch de arduino y el serverMQ"
    This reverts commit aa93296276a2d8397ba6ed18ab027592d484081c.
2014-07-12 Documentacion Agregada
    Se agrego el archivo donde van a ir los tipos de mensajes que se van a
    utilizar en la comunicacion entre el servidor y el microcontrolador y
    viceversa.
2014-07-17 Sketch de arduino modificado
    Se agrego mas comportamiento al microcontrolador y se modifico el
    archivo de texto que tiene el protocolo
2014-07-20 Se agrego package.json y .travi.yml con la configuracion minima. Se agrego la carpeta examples donde van a estar los ejemplos de prueba para probar la comunicacion con los microcontroladores durante 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
2014-07-20 Arduino puede publicar un json con sus servicios. Se agregaron topics al server. Desde el index.html de ejemplo se puede pedir a arduino que exponga los servicios que tiene
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2014-07-31 Cambios en Directorios
    Se cambio el nombre al sketch de arduino y se movio de carpeta para
    poder correr el script con inotool
2014-07-31 librerias para arduino agregadas
    se agregaron las librerias necesarias para compilar el sketch de arduino
2014-08-01 Sketch modificado
    Se agrego un LM35DZ para medir la temperatura.
    y modifique el ejemplo para agregar la medicion
2014-08-07 Agrego el git ignore antes de commitear lo demas
    es un commit previo a agregar el proyecto web hecho con yo meanjs
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2014-08-07 Agregue el modulo de configuracion el cual tendra la configuracion general de la web. De la cual se podra modificar el entorno que utiliza el usuario.
2014-08-10 Sketch modificado y schema hecho en fritzing agregado
    [Schema.fzz]
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2014-08-12 cambie las dependecias y agregue resolutions para que travis pueda compilar y correr. Las resolutions son por si bower tiene que decir versiones de lo que esta descargando.
2014-08-12 Modifique las dependencias y ahora si funciona como debe ser. Deje en la home el ejemplo
2014-08-12 Modifique la estructura del proyecto. Agregue el modulo widget y modifique el modelo.
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2014-08-14 Agregue el template del dashboard y una ruta para hacer consultas de widgets por tipo de seccion
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2014-08-17 agregue para que se cargue el archivo de estado inicial que se encuentra en la micro sd card. Puede ser que en alguna actualizacion futura se cambie el archivo por uno que tengo el estado completo de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
2014-08-18 Agregue el modulo Dispositivos, que vendrian a ser el modulo que permite bindear un controlador al sistema. Es decir, si tengo un controlador que me brinda informacion de sensores, debo agregarlo atr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
2014-08-19 Modifique el modelo de los widgets. Me falta agregar mas estilo al formulario. Tengo que agregar el crud-module de seccion. Que sirve para diferenciar las distintas secciones donde van a poder visual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
2014-08-19 Se agrego la dependencia de Bower Font-Awesome , de la cual se utilizan sus iconos nada mas. A su vez se agrego el crud-module seccion, la cual esta explicada en el commit anterior
2014-08-23 Agregada la libreria ngDialog que sirve para hacer ventanas modal. Tambien se cambio la forma en la que se carga el menu de configuracion. Falta agregar mucho estilo a la ventana modal y al menu de c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
2014-08-25 Un poco mas de estilos y logica para acomodar el menu de configuracion. Deje el menu de configuracion sin ninguna ventana modal. No quito la dependencia aun porque quizas la use en algun otro lado
2014-08-26 Un poco mas de estilos y logica para acomodar el menu de configuracion. Falta arreglar la carga de editar porque falla, el scope se pierde
2014-08-26 saque los archivos de configuracion que agregaban botones y menus a la topbar
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2014-08-26 Cambie los models de mis representaciones. Un poco mas de style v0.3
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2014-08-28 Arregle el problema que tenia al intentar editar mis modelos desde sus paginas. Era porque los $scope tiene jerarquia y los que se encuentran por debajo de esta no pueden editar los parametros de su 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
2014-08-28 Uni los 2 servers para que ahora cuando se corre el comando grunt, se corra los 2 servers dentro del mismo archivo(server.js)
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2014-08-31 Acomode el server.js para que no tire warnings. Tambien agregue para que el widget se suscriba
2014-08-31 Agregue para que ahora el widget cargue el topico al cual se suscribe.
2014-09-03 Mejore los widgets para admitir varios del mismo tipo, antes no se podia. Cuando se cargan los widgets de la db tambien se modifican sus definiciones para poder traer informacion necesario para poner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
2014-09-03 modifique el modelo del widget para que se pueda usar como definicion. Lo siguiente es agregar los dispositivos a la web y utilizar la info del topic discover para conectarse.
2014-09-04 agregue un par de cambios que permiten el uso de multiples controladores en el sistema. Falta agregar la configuracion para bindear la info del controlador a los widgets cuando se crean. Falta hacer 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
2014-09-06 modifique la web para que se vea mas info en la parte de los modelos.
    A su vez modifique el sketch de arduino que me habia olvidado de commitear, falta solucionar el problema del overflow que hay.
    Modifique la forma en que se comunican, ahora las respuestas de los controladores comienzan con resp/id_controlador/restodeltopico.
    [sketch.ino]
2014-09-06 falta hacer que se cargue el valor por defecto del widget cuando se edita
2014-09-07 Modifique el sketck de arduino para que no lea los archivos de la sd para exponer los servicios porque esta tirando overflow y se reiniciaba. Lo voy a dejar asi hasta que encuentre la solucion. Separ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
2014-09-08 pequeño fix al sketch de arduino
    [sketch.ino]
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2014-09-11 Pequeño fix de estilo
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2014-09-17 El inicio de la web se carga con la seccion Inicio, luego se cargan las demas secciones para elegir cual mostrar. Falta arreglar el select de las secciones.
2014-09-18 Agregue la navtab para las secciones creadas. Tambien volvi a modificar los modelos dado que me encontre con un problema de scope que es una porqueria. Igual ya lo solucione y funciona bien
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2014-09-23 Ahora se puede editar una seccion bien. Falta arreglar el edit de un dispositivo. Que se busquen los dispositivos y que se muestre el original
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2014-09-29 Fix de los test. Falta solucionar el chequeo de la redirreccion despues de guardar
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2014-10-07 rutas de control arregladas
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2014-10-17 Fix del estilo. Si luego de cargar el valor era cerrado, no se modificaba el color del widget.
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2014-10-21 Modificacion a la edicion de Widgets. Falta darle mas estilo y arreglar cuando se selecciona una seccion que se rompe toooodooo
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2014-10-28 Fix dependencias. Agregado para que cuando cargue el modulo de schedule corra un funcion que va a cargar las tareas en db.
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2014-10-29 pequeño fix de style
2014-10-30 Modificaciones al schema
    [Schema.fzz]
2014-11-01 Actualize la dependencia de MQTT porque tenia muchas mejoras y fixes
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2014-11-04 Fix para que la actualizacion de los datos que se muestran del scope sea mas rapida. Agregue un $digest al scope luego de cambiar los valores, esto hace que se informe y se actualize la parte visual 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
2014-11-04 Fix de la actulizacion de un dispositivo
2014-11-04 Fix de la actulizacion de un widget
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2014-11-07 modificaciones al schema de fritzing y al manual
    [Schema.fzz]
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2014-11-08 pequeño fix a la lista de secciones
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2014-11-10 arregle la relacion entre el control y el empleado
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2014-11-16 modifique el schema de fritzing y el informe final
    [Schema.fzz]
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2014-11-18 Pequeño fix al controller de configuracion ya que habia eliminado sin darme cuenta la cancelacion de las suscripciones
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2014-11-25 Solucione 2 consultas que se utilizaban para pedir los controles de empleados. Ahora esta la ruta para llegadas y para partidas arreglada
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2014-11-29 Separe el server web del broker y ademas borre un javascript que estaba demas. Tambien cambie las instrucciones para que se pueda correr desde forever
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2015-03-01 Arregle las dependecias y saque una linea de una directiva que me olvide de borrar hace un par de commits. Voy a hacer otra release despues de este commit
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2015-04-08 Agregue la seccion de problemas resueltos
